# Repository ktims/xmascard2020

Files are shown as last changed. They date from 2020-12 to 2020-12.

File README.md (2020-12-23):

# Merry Christmas 2020! 🎄🎁

If you're here, it's probably because I sent you a card/ornament and you can't get it to work, thought it might be fun to hack on, or you were curious how it was designed. Unless it's the first one, awesome!!

This was a vague idea in my head on Dec 4th, sent for manufacturing on Dec 6th, and if I managed to get it to you before Christmas, considering my projects usually go on for years and never really get 'finished', I'm super impressed with myself. Guys, I actually finished a project!! It's been a 'sprint'! I hope you enjoy it 😁.

If you just want to get hacking, download [PlatformIO](https://platformio.org/platformio-ide), check out the repo, and have a look at `code/include/Effects.h`. The only other thing you need is a 3.3V USB-serial adapter ('FTDI') and some dupont wires to hook it up. The `/code` README has more information on how to flash the board, and how the firmware works. PIO makes it super easy to set up the development environment, it's like one click, don't be scared!!

## Usage

### User Interface

There's really just one button, on the back near the top of the board and not labelled because I'm dumb. When off, press once briefly to turn on. When on, a long-press will enter brightness setting mode, and a short press will rotate between brightnesses. A long-press again will go back to normal operation. Hold for 5s and release to turn off.

You can ignore the PROG button entirely unless you're planning to hack on the firmware, it does nothing other than put it into programming mode on power up.

If untouched for ~4h it will power itself off.

### Power

**Batteries**: Battery life should be approx 30 hours while operating. After the season I suggest removing the batteries as they will run down slowly over time since there is no hard power switch (a couple years). If you need more batteries, they are readily available type CR2032. Find them at the dollar store or on Amazon. The PKCELL ones I sent are cheap on Amazon and seem to not be trash.

**External power**: 🔴🔴 **NOTE: Don't supply external power with batteries installed!** 🔴🔴 In theory you could power this with any 4-16VDC supply (@ 10mA or so). It should run reliably at 5V though, so a cheerful USB charger would be perfect. There's an external power connector on the back of the board; if I thought you might want to hook this up, I included a pigtail with the appropriate connector already on it. The connector is a JST-PH (2.0mm pitch). +/- as marked on the board.

## Design
### Hardware

Goals / Met?:
* **Cheap** / Total cost incl. expedited shipping for 10 boards was \$153 (\$15.30 ea). I think so, though I would've liked to see $10.
* **Entirely manufactured/assembled by JLCPCB** / Mostly. LEDs were hand assembled, but I didn't expect them to be manufacturable anyway as they are mounted upside down.
* **Slim for mailing** / Yes
* **Battery life >= 24h with standby life of > 1 month** / Measured operating current with the included effects at full brightness is ~4-7mA. With 220mA CR2032s, that should be 30-50h. Standby current is <5µA, which is longer than the 3y shelf-life of the batteries.
* **Light/balanced enough with batteries to hang comfortably on a tree, or sit on a small stand** / Seems to work well for me.

#### Tools

I use [KiCad EDA](https://kicad.org/) exclusively for hardware design. [Inkscape](https://inkscape.org/) was used to create the simple artwork on the silkscreen and place the LED drill hits, with [Svg2Shenzhen](https://github.com/badgeek/svg2shenzhen) to export to Kicad. [FreeCAD](https://www.freecadweb.org/) was used for 3D modeling of the stand.

#### Design decisions

##### Power supply

It needed to be battery powered, as there is no standard power source in a Christmas tree. I considered hacking in to LED christmas light bulbs to tap power, but there doesn't seem to be a standard for these and it's not a convenient way to tap power anyway, since they seem to usually be wired in series, which would require a shunt supply, and are AC which complicates too. Same problems with old-fashioned incandescents.

Which really left two choices - coin cell(s) or AAAs. AAAs have much more capacity, but have two major issues for this design: the voltage dropped over the driver and LED would require at least 3 cells (3.5V bare minimum, when near empty) or a boost converter. 3 cells (even 2) wouldn't fit within the PCB envelope, and they would be relatively heavy and likely to make it hang funny or require a large stand. So it'd have to be a single-cell solution - possible with a fancy specialized boost converter, but expensive and relatively bulky (see 'cheap' and 'slim' design goals).

I considered taping a small lithium-ion cell to the back and including a USB charger on board, but these cells are not readily available in North America and the slow boat would be too slow in this case. JLCPCB also won't assemble USB connectors, and both these and the batteries are kinda expensive. I'm not *sure* the voltage would be sufficient, either.

So two coin cells (to maximize capacity and get to the necessary voltage) it is, in the largest standard format that I could cram on the board. The disposable-ness and temporary-usefullness of this choice doesn't make me happy, but I suppose it's a bit of a disposable and temporary item anyway 😕.

Maybe the 2021 version will do something more graceful here and attempt a life beyond the holiday season 😈.

##### Microcontroller

Basically I just picked the cheapest thing on the JLCPCB Basic Parts list that I was familiar with (STM32, AVR, or MSP430) and made sure it would do the job (really the only thing that mattered much was the standby power consumption, and that it could generate a 4MHz output clock for the MBI's PWM). It is an STM32F030F4 with 16KB flash and 4KB RAM and can run at up to 48MHz. Power consumption is linear with clock rate, so I will run it at 8MHz, which is as slow as possible to be able to generate a 4MHz clock for the MBI5043 to get complete PWM cycles at 60fps (65536 * 60 = 3.93MHz). I could run it faster since it sleeps when not actively drawing a frame, and it could be similar consumption or even save power, while offering increased processing power for fancy effects (what, though?), but it will probably just make it more power hungry. Thanks physics.

##### LED Driver

I wanted at least 10 constant-current outputs, at least 10-bit PWM, and a SPI-ish interface (I2C is slow, a pain to bit-bang, and power hungry). Considering JLCPCB's parts list, the only candidate really was Macroblock MBI5043. It has a weird interface for the latch that precludes use of the hardware SPI peripheral, and not a great datasheet, but it seems simple enough to bit-bang.

##### Power control

Toggle switches are relatively expensive and can't be placed by JLCPCB assembly service, so I preferred to avoid them. That means soft power, and to minimize parts, it means the microcontroller must have a standby mode with current consumption in low µA that can wake from a button press. The STM32F030 does so (~1.7µA). It also means everything else including the 3.3V regulator and LED driver must have a low current in standby too. Hence the selection of slightly more expensive HT7533 regulator, and using a P-channel power switch for the LED driver which has no standby mode and current consumption of several mA with all LEDs off (it may be less in practice without the PWM clock running). This also enables auto-power-off.

When powered down, standby consumption comes from HT7533 (2.5µA) + STM32 (1.7µA) + Q1 leakage (100nA) is ~4.5µA standby current. This should give ~5 years standby battery life. Good enough for this purpose. The traditional 'jellybean' 1117 regulator consumes 4mA, and without the power switch on the MBI5043 (guessing 2-4mA from the datasheet), it'd probably barely last a day.

### Software

#### Toolchain / Environment

* [PlatformIO](https://platformio.org/) build tools, to make hacking more accessible and build setup easy
* [libopencm3](https://github.com/libopencm3/libopencm3) 'convenience' library to interface with the STM32 peripherals (note: PIO will pull this for you automatically). I've used this before. It's nothing special, and for what little I'm using of it here, probably didn't save much time over just writing the registers. But time is time. Sorry, I don't know Arduino and its approach is too high level for me.
* [C++17](https://en.cppreference.com/w/cpp/17). I almost tried [Rust](https://www.rust-lang.org/what/embedded) for this, but opted for something I knew at least a little bit of (and that you might know a little bit of too) due to the crunch. Sorry, you can't run Node on this hardware.

#### Structure

See `code/README.md` for more information.

The structure is fairly typical of embedded programs. Execution is driven by a 1/60s timer interrupt, which wakes the processor from sleep. The ISR for this interrupt sends a frame to the LED driver if one is ready, and the mainloop then executes to draw the next frame and handle the button. After that works is complete, the processor goes back to sleep to wait for the next frame time.

I originally envisioned swapping function pointers to implement the effects, but in classic over-engineered fashion, this lead to templated callable structs that inherit from a base `MBIEffect` class and use dynamic dispatch. Why not.

There's not much else of interest there, but I welcome harsh code reviews.

## Mistakes / Unexpectedness

* I sprung for fancy Immersion Gold finish PCBs because they'd look nicer, even though there's barely any exposed copper on the front. I should have realized this could be used for the artwork and gold-on-black would be much blingier than white-on-black, or even 3-colour art!
* I did not think to match the LED reference designations with their output # / buffer index. At least it's only an off-by-one since the references are 1-indexed rather than random.
* 3 weeks is not enough time to design boards, have them made and delivered, write software, and then deliver to recipients. Not enough time *at all*.
* Read the datasheets *carefully*. The pin I wired up as the PWM clock does indeed operate as a timer output, but only on some device variants, and not the one I have. Could've just used one of the free pins instead...this is why there is a bodge wire on your board.
* These 'lighting' LEDs are...melty... They tolerate almost no heat from the soldering iron. Not used to components being made with thermoplastics.

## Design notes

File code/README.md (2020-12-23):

# Development Environment

## Software Dev Env

The project is based on [PlatformIO](https://platformio.org/), which should more or less do everything for you magically. I recommend the [VSCode integration](https://platformio.org/platformio-ide).

1. Install PlatformIO (ie. the VSCode extension of the same name)
2. Clone the repository
3. `git submodule update --init`
4. Open the `code` directory in VSCode
5. PlatformIO will install a bunch of stuff under the covers, but eventually you should be able to successfully execute the `PlatformIO: Build` command in VSCode.

## Programming the flash

The simplest way to program the hardware is using the serial bootloader, and this is how the PlatformIO project is setup. You will need:

* USB-serial converter capable of 3.3V levels (easily had on AliExpress or eBay for ~$1)
* Some Dupont-style hookup wires. Probably you will want male-female ones.
* Optionally pin headers to solder on the board.

Edit `platformio.ini` and look for `upload_port`. Set this to the appropriate port for your platform & serial converter (e.g. `COM3` or `/dev/ttyUSB0`).

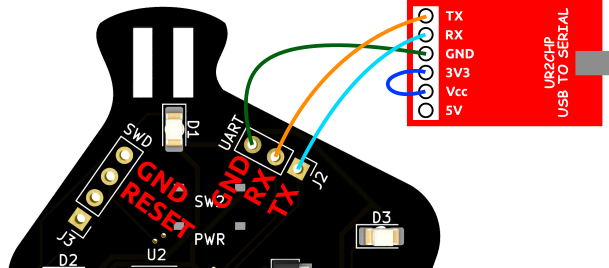
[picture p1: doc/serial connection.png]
serial connection
1. Hook it up like this (stupidly I didn't mark the pins on the PCB): 
2. Boot into the bootloader - to do this either hold the PROG button while applying power, or hold the PROG button while shorting RESET to GND (use a wire) and letting float. The LEDs should stay off.
3. Execute `PlatformIO: Upload` in VSCode

## Debugging

The SWD header can be used with an ST-Link debugger. Ostensibly, anyway. I wasn't able to get it to work when the microcontroller is in sleep mode (which is almost all of the time). PlatformIO supports this and I did use it successfully with the STM32F103 on the board I was using for dev before the PCBs came in.

In `config.h` there is a `DEBUG` define, if this is set non-zero, the serial port will also be initialized after boot, which you can open with a normal terminal application at 115200bps 8N1. The `debug_str` function will be available if `DEBUG` is defined, to print simple strings to the serial port for debugging.

# Architecture

Execution is driven by the Cortex M0 SysTick timer that ticks at 1/60s. When this timer fires, the interrupt handler has the MBI5043 driver write the buffer to the LED array (in interrupt context), so the framerate should be pretty tightly timed. A flag is set, and execution returns to the main loop. The main loop calls out to the effect to draw the next frame, then handles button input. When its work is done, it puts the microcontroller to sleep, waiting for the next SysTick interrupt. For power off, mainloop returns, and the processor is put into 'deep sleep' standby mode. On wakeup from this mode, the processor will be totally reset, so it will be identical to booting from fresh.

Effects are implemented as sub-classes of `MBIEffect`. The only required member function is `void operator(MBI& mbi, const uint32_t frames)`. This function receives a reference to the MBI5043 driver, and the current frame counter. It should call `mbi.get_buffer()` to get a reference to an array of `uint16_t` representing the LEDs, and modify it as appropriate. Values should span the full `uint16_t` range; they will be scaled and gamma corrected at output time.

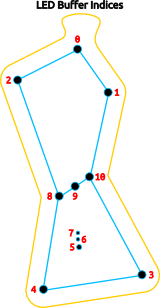
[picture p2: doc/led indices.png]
LED buffer indices


After implementing your effect class, it must be instantiated (in `EffectSetup.h`) and included in the `effects` array found in `main.cpp`.

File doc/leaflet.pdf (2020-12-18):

# Hi, I'm a Bauble!

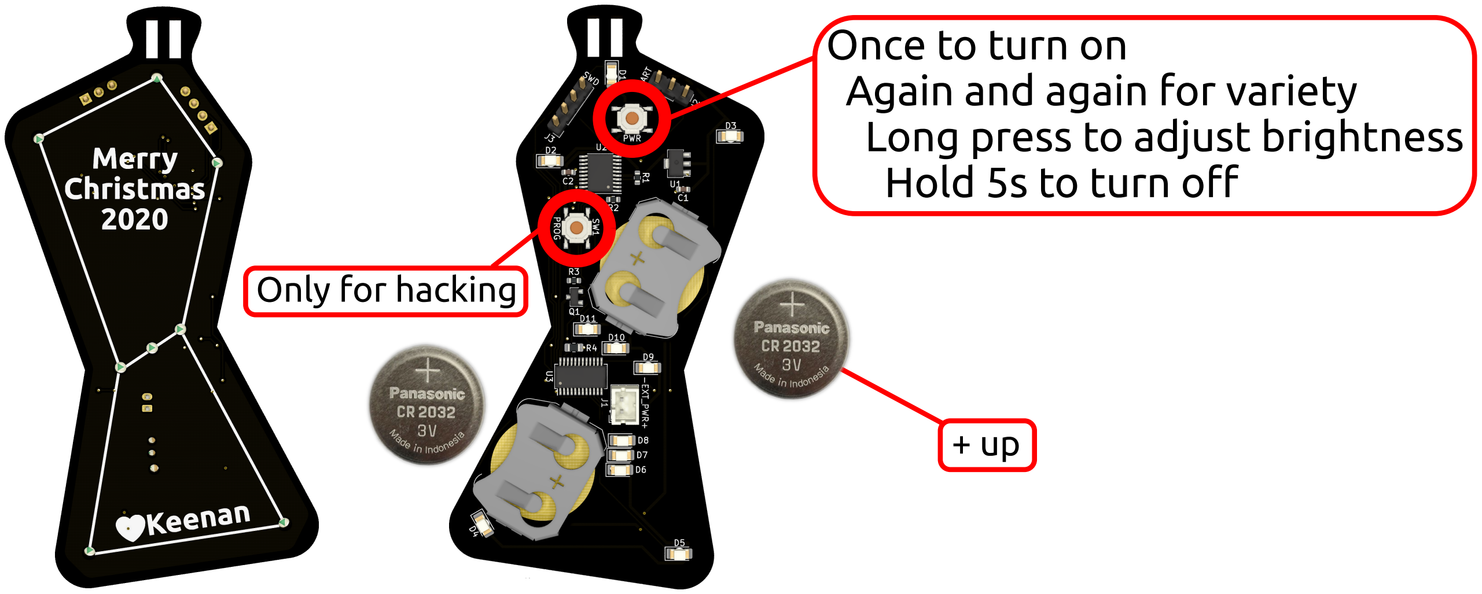
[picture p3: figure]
Once to turn on Again and again for variety Long press to adjust brightness Hold 5s to turn off; Only for hacking
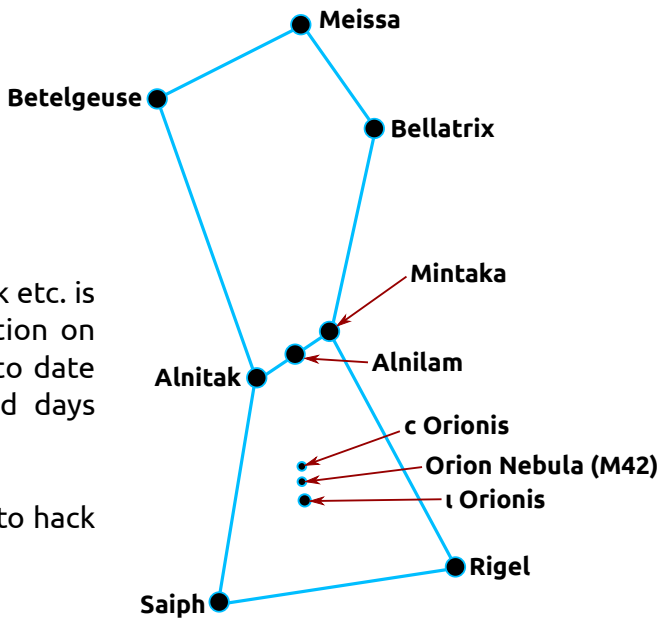
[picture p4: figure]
Betelgeuse; Rigel; Bellatrix; Alnilam Alnitak; Saiph; Mintaka; ι Orionis; Orion Nebula (M42); Meissa; c Orionis

https://github.com/ktims/xmascard2020

All the hardware design files, code, and random artwork etc. is up on GitHub, as well as some additional documentation on the design/build process and usage, which will be up to date with what you actually receive (this is being printed days before).

If you're at all interested in hardware, I encourage you to hack on this. I've tried to make it really easy!

## Tech Specs

Batteries: 2xCR2032 (3V)
Battery life: ~30h
Compute: ~20x the Apollo Guidance Computer Memory: ROM: 1/2xAGC (16KB) RAM: 1xAGC (4KB) LEDs: 11 driven @ 60fps with 16-bit PWM

Everybody knows I fiddle with electronics. Rarely does anyone see any of that stuff. Today, that changes! Making this was merely a vague idea in my head on Dec 4th, sent to fab Dec 6th, and hopefully made it into your hands before Dec 25th. It's been a crunch, but fun to work on something someone else might appreciate.

It depicts the constellation Orion, the stalwart hunter of the winter night sky; an ancient and secular symbol of winter we're all very familiar with. May his presence brighten your holiday season and inspire you to look up on those crisp, clear winter nights.

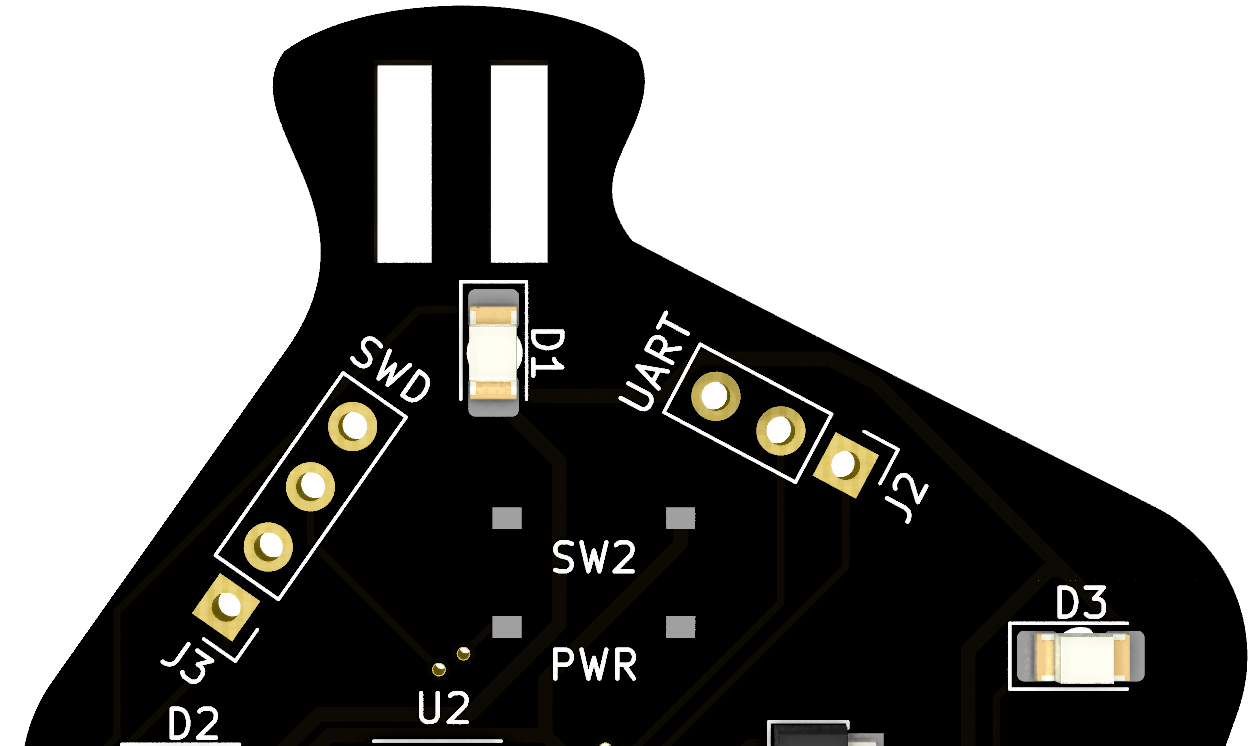
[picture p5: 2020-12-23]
doc/rear-ports.png

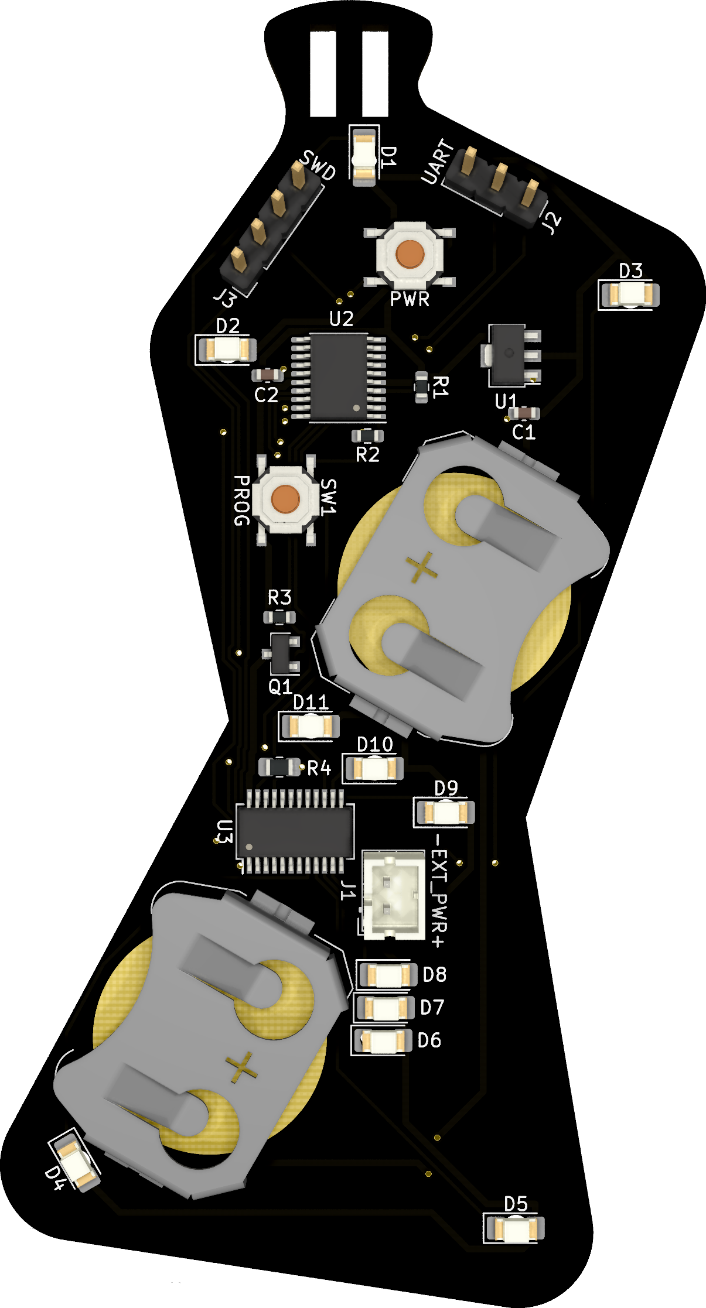
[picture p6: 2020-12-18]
art/board_rear_3d.png

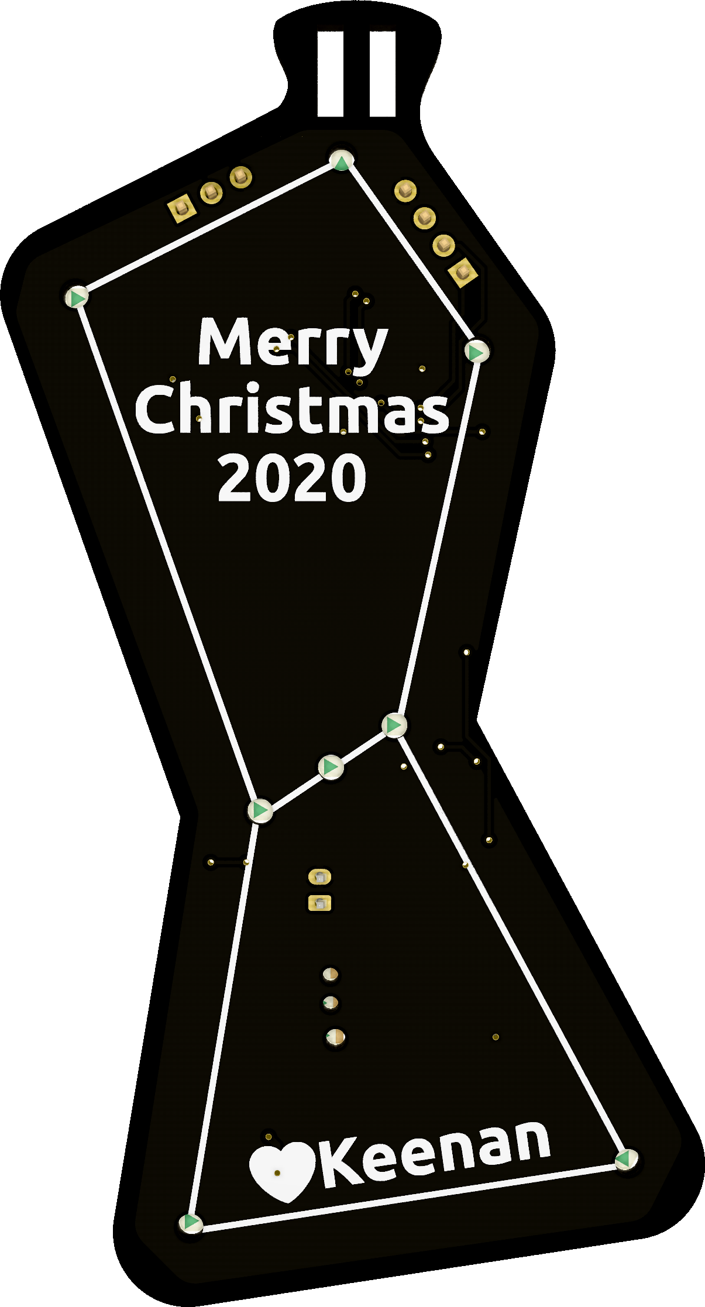
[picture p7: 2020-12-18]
art/board_front_3d.png

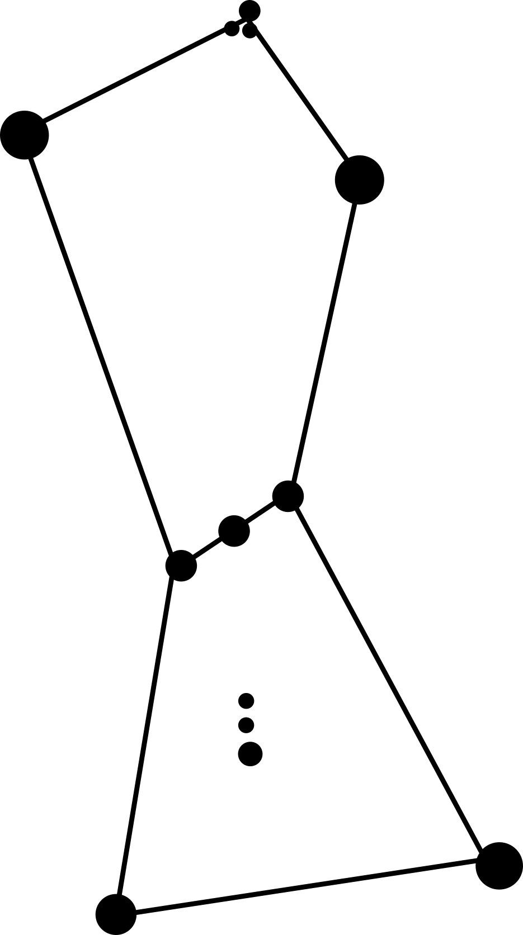
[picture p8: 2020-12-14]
art/orion.png

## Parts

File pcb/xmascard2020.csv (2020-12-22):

Comment | Designator | Footprint | LCSC
CR2032 | BT1,BT2 | Battery:BatteryHolder_Keystone_3034_1x20mm
10u | C1,C2 | Capacitor_SMD:C_0603_1608Metric
LED | D1,D2,D3,D4,D5,D6,D7,D8,D9,D10,D11 | LED_SMD:LED_1206_3216Metric_Pad1.42x1.75mm_HandSolder
EXT_PWR | J1 | Connector_JST:JST_PH_B2B-PH-K_1x02_P2.00mm_Vertical
UART | J2 | Connector_PinHeader_2.54mm:PinHeader_1x03_P2.54mm_Vertical
SWD | J3 | Connector_PinHeader_2.54mm:PinHeader_1x04_P2.54mm_Vertical
AO3401A | Q1 | Package_TO_SOT_SMD:SOT-23 | C15127
100k | R1,R2,R3 | Resistor_SMD:R_0603_1608Metric
2.7k | R4 | Resistor_SMD:R_0805_2012Metric_Pad1.20x1.40mm_HandSolder | C17530
PROG | SW1 | projlib:TS-1187A | C318884
PWR | SW2 | projlib:TS-1187A | C318884
HT7533-1 | U1 | Package_TO_SOT_SMD:SOT-89-3 | C14289
STM32F030F4Px | U2 | Package_SO:TSSOP-20_4.4x6.5mm_P0.65mm | C89040
MBI5043GP | U3 | Package_SO:SSOP-24_3.9x8.7mm_P0.635mm | C110098

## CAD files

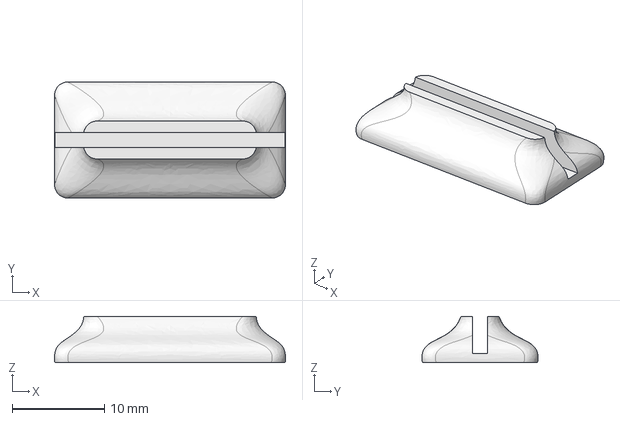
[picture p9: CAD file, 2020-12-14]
stand/xmascard2020 stand.FCStd
25.1 x 12.6 x 5.00 mm

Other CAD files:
stand/xmascard2020 stand.3mf
stand/xmascard2020 stand.stl

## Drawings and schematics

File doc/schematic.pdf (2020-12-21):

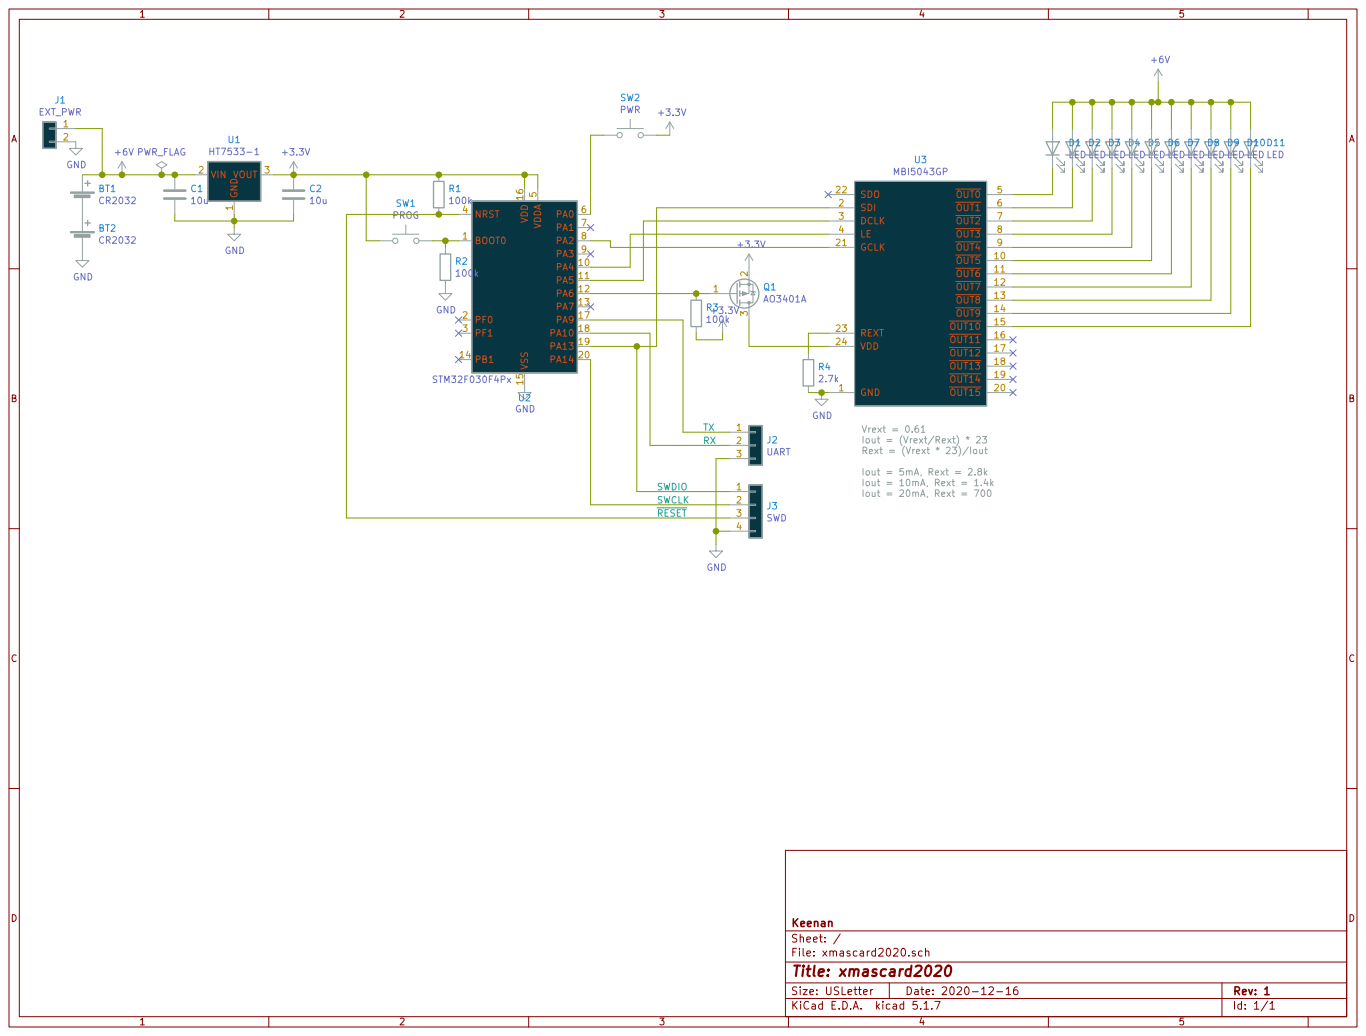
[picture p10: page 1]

5 PA0 6 PA1 7 PA2 8 PA3 9 U2 STM32F030F4Px SW2 PWR GND 1 OUT5 10 OUT6 11 OUT7 12 OUT8 13 OUT9 14 OUT10 15 OUT11 16 OUT12 17 OUT13 18 OUT14 19 SDI 2 OUT15 20 GCLK 21 SDO 22 REXT 23 VDD 24 DCLK 3

1 VIN 2 VOUT 3 U1 HT7533-1 GND GND

File: xmascard2020.sch Sheet: / Keenan

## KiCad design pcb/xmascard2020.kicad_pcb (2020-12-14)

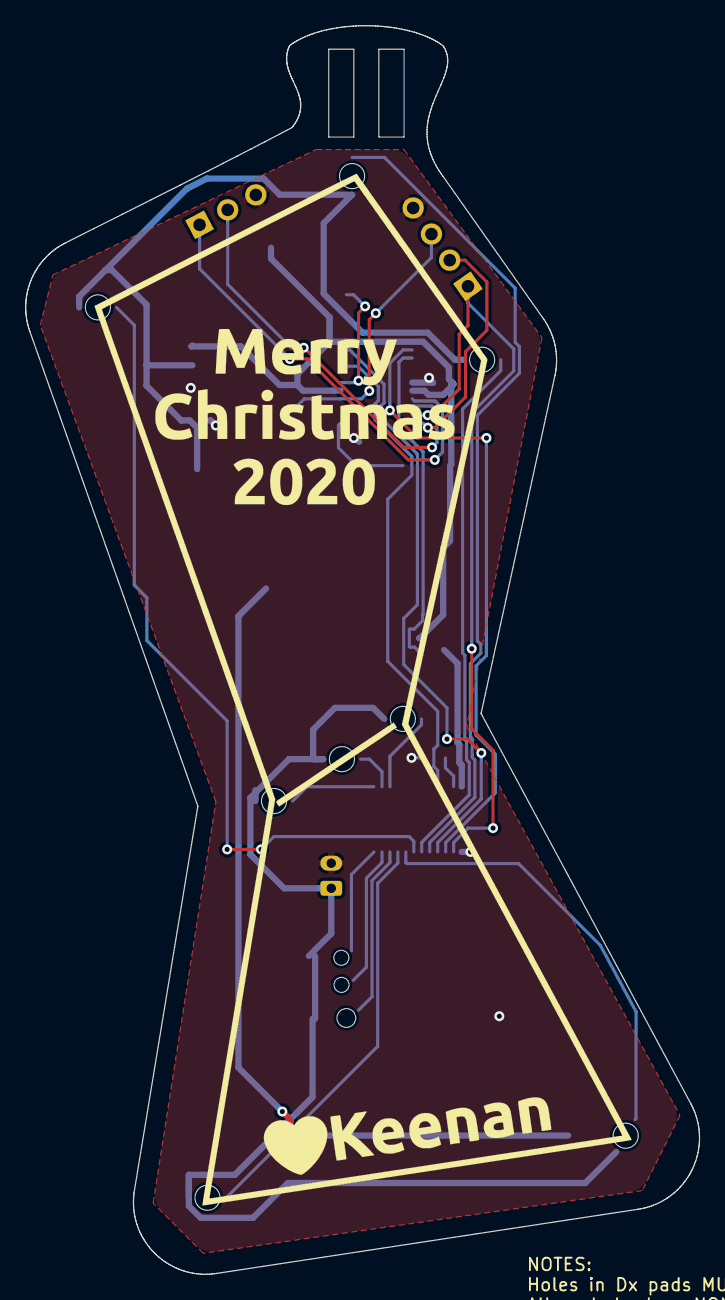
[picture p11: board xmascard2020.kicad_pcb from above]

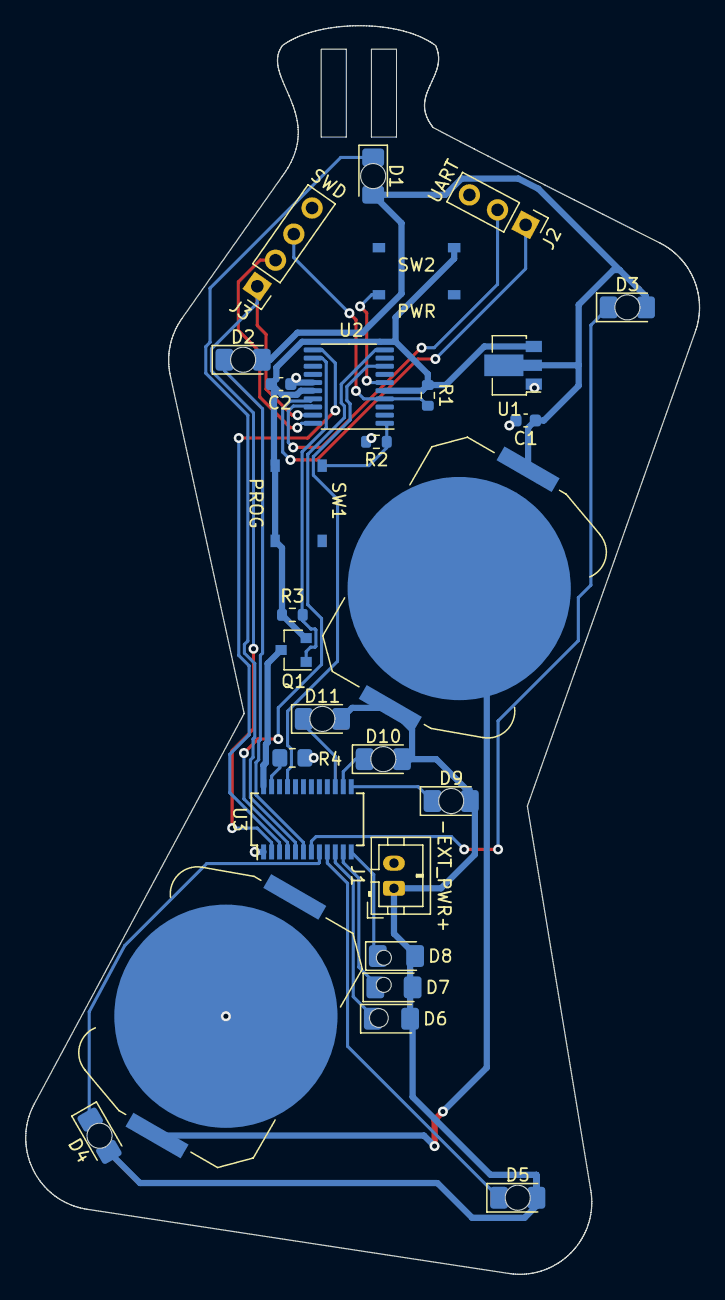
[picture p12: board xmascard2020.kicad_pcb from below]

Board: 2 copper layers, 53.7 x 99.6 mm, 29 parts (28 on the bottom side), 28 nets.

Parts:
ARTWORK: Val**; orion
BT1, BT2: CR2032; BatteryHolder_Keystone_3034_1x20mm
C1, C2: 10u; C_0603_1608Metric
D1, D2, D3, D4, D5, D6, D7, D8, D9, D10, D11: LED; LED_1206_3216Metric_Pad1.42x1.75mm_HandSolder
J1: -EXT_PWR+; JST_PH_B2B-PH-K_1x02_P2.00mm_Vertical
J2: UART; PinHeader_1x03_P2.54mm_Vertical
J3: SWD; PinHeader_1x04_P2.54mm_Vertical
Q1: AO3401A; SOT-23
R1, R2, R3: 100k; R_0603_1608Metric
R4: 2.8k; R_0805_2012Metric_Pad1.20x1.40mm_HandSolder
SW1: PROG; TS-1187A
SW2: PWR; TS-1187A
U1: HT7533-1; SOT-89-3
U2: STM32F030F4Px; TSSOP-20_4.4x6.5mm_P0.65mm
U3: MBI5043GP; SSOP-24_3.9x8.7mm_P0.635mm

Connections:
+3V3: C2.1, Q1.2, R1.1, R3.2, SW1.1, SW2.2, U1.3, U2.5, U2.16
+6V: BT1.1, C1.1, D1.2, D2.2, D3.2, D4.2, D5.2, D6.2, D7.2, D8.2, D9.2, D10.2, D11.2, J1.1, U1.2
/RX: J2.2, U2.18
/SWCLK: J3.2, U2.20
/SWDIO: J3.1, U2.19, U3.2
/TX: J2.1, U2.17
/~RESET: J3.3, R1.2, U2.4
GND: BT2.2, C1.2, C2.2, J1.2, J2.3, J3.4, R2.2, R4.2, U1.1, U2.15, U3.1
unnamed: BT1.2, BT2.1
unnamed: D1.1, U3.5
unnamed: D2.1, U3.6
unnamed: D3.1, U3.7
unnamed: D4.1, U3.8
unnamed: D5.1, U3.9
unnamed: D6.1, U3.10
unnamed: D7.1, U3.11
unnamed: D8.1, U3.12
unnamed: D9.1, U3.13
unnamed: D10.1, U3.14
unnamed: D11.1, U3.15
unnamed: Q1.1, R3.1, U2.12
unnamed: Q1.3, U3.24
unnamed: R2.1, SW1.2, U2.1
unnamed: R4.1, U3.23
unnamed: SW2.1, U2.6
unnamed: U2.8, U3.21
unnamed: U2.10, U3.4
unnamed: U2.11, U3.3

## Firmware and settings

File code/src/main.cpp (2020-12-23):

#include <algorithm>
#include <array>
#include <cstdint>
#include <functional>
#include <string>

#include <libopencm3/stm32/exti.h>
#include <libopencm3/stm32/gpio.h>
#include <libopencm3/stm32/pwr.h>
#include <libopencm3/stm32/rcc.h>
#include <libopencm3/stm32/timer.h>
#include <libopencm3/stm32/usart.h>

#include <libopencm3/cm3/nvic.h>

#include <libopencm3/cm3/systick.h>

#include "config.h"
#include "optimizations.h"

#include "EffectSetup.h"
#include "MBI5043.h"
#include "util.h"

#ifdef DEBUG
#include <cstdio>
#endif

// MBI5043 LED driver instance
mbi_t mbi(GPIO_PORT, MBI_LE, MBI_DCLK, MBI_SDI, LED_OUT_MAX);

// Frame counter
uint32_t frame = 0;

// Auto power off when we get to this frame
uint32_t apo_frame = APO_FRAMES;

// Signal between interrupt-driven frame drawing and main loop when it's time to draw the next frame. This variable is
// stupidly named, when true it represents that a frame has been written to the LEDs and the buffer is ready for the
// next one
volatile bool frame_drawn = true;

// Enabled effects
const std::array<effect_ref, 5> effects = {
    TwinkleBlinkle,
    RandomSequence,
    ChaseRandom,
    TwinkleTwinkle,
    ChaseAround,
};

uint8_t cur_effect = 0;
uint8_t cur_bright = 6;

// This is a reference to the MBIEffect instance that will be drawn in the mainloop, it may differ from cur_effect for
// menus etc.
auto draw_frame = effects[0];

enum menu_state_t { MAIN, BRIGHT };

// Set up system clocks
void clock_setup()
{
    rcc_periph_clock_enable(RCC_GPIOA);
    systick_set_frequency(FPS, F_CPU);
}

// Set up GPIO & alternate functions
void io_setup()
{
    // The libopencm3 API is slightly different for different processor families.
#ifdef STM32F0
    // Set up GPIO outputs
    gpio_mode_setup(GPIO_PORT, GPIO_MODE_OUTPUT, GPIO_PUPD_NONE, MBI_DCLK | MBI_LE | MBI_PWR | MBI_SDI);
    gpio_set_output_options(GPIO_PORT, GPIO_OTYPE_PP, GPIO_OSPEED_25MHZ, MBI_DCLK | MBI_LE | MBI_PWR | MBI_SDI);

    // Set up GPIO inputs with pull-down
    gpio_mode_setup(GPIO_PORT, GPIO_MODE_INPUT, GPIO_PUPD_PULLDOWN, PWR_SW);

    // Set up USART IOs
    gpio_mode_setup(GPIO_PORT, GPIO_MODE_AF, GPIO_PUPD_NONE, UART_RX | UART_TX);
    gpio_set_af(GPIO_PORT, GPIO_AF1, UART_TX | UART_RX);

    // Set up GCLK output
    gpio_mode_setup(GPIO_PORT, GPIO_MODE_AF, GPIO_PUPD_NONE, MBI_GCLK);
    gpio_set_af(GPIO_PORT, GPIO_AF4, MBI_GCLK);

#elif STM32F1
    rcc_periph_clock_enable(RCC_AFIO);
    gpio_set_mode(GPIO_PORT, GPIO_MODE_OUTPUT_10_MHZ, GPIO_CNF_OUTPUT_PUSHPULL, MBI_DCLK | MBI_LE | MBI_PWR | MBI_SDI);

    gpio_set_mode(GPIO_PORT, GPIO_MODE_INPUT, GPIO_CNF_INPUT_PULL_UPDOWN, PWR_SW);

    gpio_set_mode(GPIO_PORT, GPIO_MODE_OUTPUT_10_MHZ, GPIO_CNF_OUTPUT_ALTFN_PUSHPULL, UART_TX);
    gpio_set_mode(GPIO_PORT, GPIO_MODE_INPUT, GPIO_CNF_INPUT_FLOAT, UART_RX);

    gpio_set_mode(GPIO_PORT, GPIO_MODE_OUTPUT_10_MHZ, GPIO_CNF_OUTPUT_ALTFN_PUSHPULL, MBI_GCLK);

#else
#error "No GPIO setup for this STM32 family (or undefined family macro)"
#endif
}

#if DEBUG > 0
// Set up USART1 to transmit debug messages at 115200bps
void uart_setup()
{
    rcc_periph_clock_enable(RCC_USART1);
    usart_set_baudrate(USART1, UART_SPEED);
    usart_set_databits(USART1, 8);
    usart_set_parity(USART1, USART_PARITY_NONE);
    usart_set_stopbits(USART1, USART_CR2_STOPBITS_1);
    usart_set_mode(USART1, USART_MODE_TX_RX);
    usart_set_flow_control(USART1, USART_FLOWCONTROL_NONE);

    usart_enable(USART1);
}
#else
void uart_setup() { }
#endif

// Set the GPIO that controls the PFET power switch to MBI5043
// This device has a documented quiescent current of multiple mA, which is way too high when we need a standby current
// of µA when off.
void mbi_power(bool on)
{
    if (on)
        gpio_clear(GPIO_PORT, MBI_PWR);
    else
        gpio_set(GPIO_PORT, MBI_PWR);
}

// SysTick ISR
// When we hit the frame timer, and there's a frame ready for us, draw it and signal back
void sys_tick_handler(void)
{
    if (!frame_drawn) {
        mbi.put_frame<ENABLE_GAMMA>();
        frame_drawn = true;
    }
    // Increment regardless of whether we actually drew a frame to the buffer, this is our timekeeping
    frame++;
}

void board_init()
{
    clock_setup();
    io_setup();
    uart_setup();

    mbi_power(true);

    nvic_enable_irq(NVIC_SYSTICK_IRQ);
    systick_clear();
    systick_interrupt_enable();
    systick_counter_enable();
}

void set_effect(const uint8_t i)
{
    cur_effect = i % effects.size();
    draw_frame = effects[cur_effect];
    mbi.clear_buffers();
}

menu_state_t press_main()
{
    set_effect(cur_effect + 1);
    return MAIN;
}
menu_state_t press_bright()
{
    cur_bright = cur_bright == 0 ? 6 : cur_bright - 1;
    mbi.bright = (static_cast<uint32_t>(1) << (cur_bright + 9)) - 1;

    indicator.n = cur_bright + 1;
    draw_frame = indicator;
    return BRIGHT;
}

menu_state_t long_press_main()
{
    indicator.n = cur_bright + 1;
    draw_frame = indicator;
    return BRIGHT;
}
menu_state_t long_press_bright()
{
    set_effect(cur_effect);
    return MAIN;
}

// Called after initialization. To 'request' a power off, mainloop returns, and the caller will power off the CPU or
// whatever
void mainloop()
{
    enum sw_state_t { WAITING, PRESSED, RELEASED, POWER_OFF_DELAY };

    sw_state_t sw_state = RELEASED; // Button will be pressed on power up, so ignore it for a bit
    menu_state_t menu_state = MAIN;
    size_t frames_held = 0;

    while (true) {
        if (frame_drawn) {
            draw_frame(mbi, frame);
            frame_drawn = false;
        }

        // Do button i/o lazily in the main loop.
        // This breaks badly if processing a frame takes longer than 1 frame, so don't do that
        bool sw = gpio_get(GPIO_PORT, PWR_SW);

        if (sw)
            apo_frame = frame + APO_FRAMES;

        if (frame == apo_frame) {
            // it's possible that we miss this, if frame generation is taking too long but doing >= instead means we
            // have to handle overflow
            return;
        }

        switch (sw_state) {
        case WAITING:
            if (sw) {
                sw_state = PRESSED;
                frames_held = 1;
            }
            break;
        case PRESSED:
            // If the switch is still held, don't act yet, but update the display to show we received the input
            if (sw) {
                frames_held++;
                if (frames_held >= PWR_PRESS) {
                    // Turn off all the LEDs to indicate we are about to turn off
                    draw_frame = AllOff;
                } else if (frames_held > LONG_PRESS) {
                    // Turn on one LED to indicate we received the long-press
                    indicator.n = 1;
                    draw_frame = indicator;
                }
            } else {
                if (frames_held <= LONG_PRESS) {
                    debug_str("Short press detected\n");
                    switch (menu_state) {
                    case MAIN:
                        menu_state = press_main();
                        break;
                    case BRIGHT:
                        menu_state = press_bright();
                        break;
                    }
                } else if (frames_held >= PWR_PRESS) {
                    // I would rather this happened immediately when the button has been held for a few
                    // seconds, but this causes the processor to be unable to wake up
                    debug_str("Waiting to standby\n");
                    sw_state = POWER_OFF_DELAY;

                    break;
                } else {
                    debug_str("Long press detected\n");
                    switch (menu_state) {
                    case MAIN:
                        menu_state = long_press_main();
                        break;
                    case BRIGHT:
                        menu_state = long_press_bright();
                        break;
                    }
                }
                sw_state = RELEASED;
                frames_held = 0;
            }
            break;
        case RELEASED:
            frames_held++;
            // DEBOUNCE_DELAY dead frames before we accept button presses again
            if (frames_held >= DEBOUNCE_DELAY) {
                sw_state = WAITING;
                frames_held = 0;
            }
            break;

        case POWER_OFF_DELAY:
            frames_held++;
            // Wait DEBOUNCE_DELAY frames after PWR_SW released to make sure it has settled before powering off
            if (frames_held >= DEBOUNCE_DELAY) {
                debug_str("Mainloop returning to enter standby\n");
                return;
            }
            break;
        }

        // Sleep until the next frame interrupt
        cpu_sleep();
    }
}

int main(void)
{
    debug_str("main entered\n");
    board_init();
    debug_str("board inited\n");

#if DEBUG > 0
    char buf[128];
    snprintf(buf, 128, "\n\nGamma approximation coefficients (float32):\n");
    debug_str(buf);
    for (auto i = 0U; i < mbi.gamma_coeffs.size(); i++) {
        const unsigned char* c = (const unsigned char*)(&mbi.gamma_coeffs[i]);
        snprintf(buf, 128, "\t%i: 0x%02x%02x%02x%02x\n", i, *c, *(c + 1), *(c + 2), *(c + 3));
        debug_str(buf);
    }
#endif
    mbi.config = (mbi.config
                     & ~(_BV(mbi_t::GAIN_B0) | _BV(mbi_t::GAIN_B1) | _BV(mbi_t::GAIN_B2) | _BV(mbi_t::GAIN_B3)
                         | _BV(mbi_t::GAIN_B4) | _BV(mbi_t::GAIN_B5)))
        | (MBI_GAIN << 4); // set only the gain bits to the configured current gain
    mbi.config |= _BV(mbi_t::GCLK_DDR); // and enable clock doubling mode
    mbi_power(true);
    mbi.start();
    debug_str("MBI5043 started\n");

    effect_rng.seed(get_true_random);

    set_effect(std::uniform_int_distribution<uint8_t>(0, effects.size() - 1)(effect_rng));

    mainloop();

    mbi.stop();
    mbi_power(false);
    cpu_off(); // This will not return, since the device's registers and SRAM are reset after wakeup from deep sleep
    debug_str("Here be dragons\n");
}

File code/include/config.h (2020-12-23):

#pragma once

#include <array>

#include <libopencm3/stm32/gpio.h>
#include <libopencm3/stm32/pwr.h>
#include <libopencm3/stm32/rcc.h>
#include <libopencm3/stm32/timer.h>

// Enable serial debug outputs
// constexpr auto DEBUG

// Enable 'optimized' versions of library functions in optimizations.h to save
// time and space
#define OPTIMIZATIONS

#define DEBUG 0

// UART baud rate
constexpr auto UART_SPEED = 115200;

// Number of LEDs attached to MBI
constexpr auto NUM_LEDS = 11;

// Maximum LED brightness value. Appled at output, doesn't affect effects
constexpr uint16_t LED_OUT_MAX = 65535;

// MBI current gain. See datasheet page 16. 0 = 1/8x, 0b11111 = 1.938x. R4 (2.7k) sets the base value to 5.2mA
constexpr uint8_t MBI_GAIN = 0;

// Frames to draw per second
constexpr auto FPS = 60;

// Long presses are >= LONG_PRESS & < PWR_PRESS
constexpr size_t LONG_PRESS = FPS / 2; // 500ms

// Power presses are >= PWR_PRESS
constexpr size_t PWR_PRESS = FPS * 3; // 3s

// Debounce delay after button input before accepting another input
constexpr size_t DEBOUNCE_DELAY = FPS / 20; // ~50ms

// Auto power off delay after no input
constexpr uint32_t APO_FRAMES = FPS * 4 * 3600; // 4 hours

// LED chase order (zig-zag starting bottom right) - cap at NUM_LEDS for one
// direction NOTE TO SELF: Next time make the Dx numbers match the output pin
// numbers 🤦
[[maybe_unused]] constexpr std::array LED_ORDER
    = { 3U, 4U, 5U, 6U, 7U, 8U, 9U, 10U, 1U, 0U, 2U, 8U, 9U, 10U };

//
constexpr bool ENABLE_GAMMA = true;
// Gamma correction exponent
constexpr float GAMMA = 2.8;
// Gamma correction estimation degree/accuracy (only 3 supported for now)
constexpr int GAMMA_DEGREE = 3;

// Platform specific configurationf follows (pin/timer setup)

// Default hardware platform is STM32F0
#ifdef STM32F0
// IO layout:
//   PA0  : input/WKUP <- PWR switch
//   PA1  : n/c
//   PA2  : unusable   -- Bodged to PA7 which has a working timer output
//   PA3  : n/c
//   PA4  : output     -> MBI5043 LE, LED driver latch
//   PA5  : output     -> MBI5043 DCLK, LED driver serial clock
//   PA6  : output     -> Power switch for MBI5043
//   PA7  : TIM14_CH1  -> TIM14 CH1 output to generate PWM clock for LED driver
//   PA9  : USART1_TX  -> UART for application & bootloader
//   PA10 : USART1_RX  <- UART for application & bootloader
//   PA13 : output     -> MBI5043 SDI, LED driver serial data
//   PA14 : unused     -> SWDIO debugger pin, could be used
//   PB1  : n/c
//   PF0  : n/c
//   PF1  : n/c

constexpr auto GPIO_PORT = GPIOA;

constexpr auto PWR_SW = GPIO0;
constexpr auto PWR_SW_WKUP = PWR_CSR_EWUP1;

// NB: This isn't actually generalized since we are not capturing the AF setting here
constexpr auto MBI_GCLK = GPIO7;
constexpr auto MBI_GCLK_TIMER = TIM14;
constexpr auto MBI_GCLK_TIMER_RCC = RCC_TIM14;

constexpr auto MBI_LE = GPIO4;
constexpr auto MBI_DCLK = GPIO5;

constexpr auto MBI_SDI = GPIO13;
constexpr auto MBI_PWR = GPIO6;

constexpr auto UART_TX = GPIO9;
constexpr auto UART_RX = GPIO10;

// Some defines are different on dev platform STM32F1
#elif STM32F1 // for dev on STM32F103 board
constexpr auto MBI_SDI = GPIO12;
constexpr auto MBI_GCLK = GPIO6;
constexpr auto MBI_GCLK_TIMER = TIM3;
constexpr auto MBI_GCLK_TIMER_RCC = RCC_TIM3;

constexpr auto GPIO_PORT = GPIOA;

constexpr auto PWR_SW = GPIO0;
constexpr auto PWR_SW_WKUP = PWR_CSR_EWUP;

constexpr auto MBI_LE = GPIO4;
constexpr auto MBI_DCLK = GPIO5;

constexpr auto MBI_PWR = GPIO6;

constexpr auto UART_TX = GPIO9;
constexpr auto UART_RX = GPIO10;
#endif

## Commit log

2020-12-14 Initial commit of all the things
    [xmascard2020 stand.FCStd, xmascard2020.kicad_pcb, xmascard2020.sch]
2020-12-17 Add 3d model to pushbutton footprint
2020-12-18 Add 3D renders of front and back of board
2020-12-18 Add 'stand' manufacturing artifacts
    [xmascard2020 stand.3mf, xmascard2020 stand.stl]
2020-12-22 Add production outputs to repo
    [xmascard2020-B_Cu.gbr, xmascard2020-B_Mask.gbr, xmascard2020-B_Paste.gbr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]
